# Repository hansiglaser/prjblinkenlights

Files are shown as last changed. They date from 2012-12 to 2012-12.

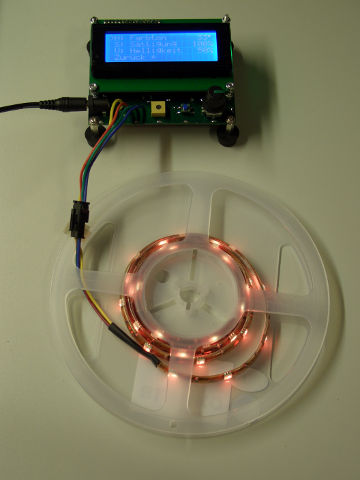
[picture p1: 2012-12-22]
doc/PrjBlinkenlights.360x480.jpg

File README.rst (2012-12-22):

Project Blinkenlights -- RGB LED Strip Controller
=================================================

**Project Blinkenlights** is a RGB LED strip controller. This repository
includes its hardware and firmware.



License
-------

    Copyright (C) 2012 Johann Glaser <Johann.Glaser@gmx.at>

    This program is free software; you can redistribute it and/or modify  
    it under the terms of the GNU General Public License as published by
    the Free Software Foundation; either version 2 of the License, or  
    (at your option) any later version.

    This program is distributed in the hope that it will be useful,
    but WITHOUT ANY WARRANTY; without even the implied warranty of
    MERCHANTABILITY or FITNESS FOR A PARTICULAR PURPOSE.  See the
    GNU General Public License for more details.

    You should have received a copy of the GNU General Public License along
    with this program; if not, write to the Free Software Foundation, Inc.,
    51 Franklin Street, Fifth Floor, Boston, MA 02110-1301 USA.

The repository includes several datasheets. Their copyright belongs to their
respective owners and are only replicated here for easier access.

The name **Project Blinkenlights** is used by numerous other organizations,
products and initiatives. This RGB LED strip controller does not have to do
anything with them. No rights on the name are requested.

Language
--------

**Project Blinkenlights** is developed for German speaking users. Therefore
its user interface and its `user manual
<prjblinkenlights/blob/master/doc/Betriebsanleitung.pdf?raw=true>`_ use the German
language. Nevertheless, all firmware source files and all hardware design
files are written in English.

Directory Structure
-------------------

  ``doc/``
    Documentation

  ``eagle/``
    Hardware design files

  ``datasheets/``
    Datasheets of the components used in the hardware design

  ``workspace/``
    Eclipse workspace with numerous testing projects

  ``workspace/PrjBlinkenlights/``
    The main Eclipse project with the full firmware

Hardware
--------

The hardware of **Project Blinkenlights** uses a TI LaunchPad MSP-EXP430 Rev.
1.5. A custom BoosterPack (see its `design files
<prjblinkenlights/tree/master/eagle/>`_) provides the facilities to control
the device, switch the LEDs, and hold an LCD display.

The LaunchPad holds an MSP430G2553 microcontroller.

Build
-----

The MSP430 microcontroller is programmed using ``msp430-gcc`` and
``mspdebug``. For details on the tool installation in Debian GNU/Linux see
my `blog post
<http://johann-glaser.blogspot.co.at/2012/10/msp430-launchpad-with-debian.html>`_.

An Eclipse workspace was created and used seamlessly with these tools for
compiling and debugging. More details to follow.

TODO
----

 - Firmware: update documentation in main.c
 - BoosterPack: change layer of wires to the LaunchPad connectors from bottom
   to top
 - Documentation: how to use Eclipse with MSP430
 - Documentation: design decisions, ideas, ... (see Zim)

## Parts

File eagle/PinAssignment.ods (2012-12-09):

Port | Timer | LaunchPad | Idee | Signal | Direction
P1.0 |  | LED gn | LCD-RS | LCD-RS | O
P1.1 | TA0.0 |  | LCD-R/W | LCD-R/W | O
P1.2 | TA0.1 |  | LCD-E | LCD-E | O
P1.3 |  | Button | PUSH | PUSH | I
P1.4 |  |  | ROTENC-A | ROTENC-A | I
P1.5 | TA0.0 |  | ROTENC-B | ROTENC-B | I
P1.6 | TA0.1 | LED rt | GATE-LCD | GATE-LCD | O | PWM
P1.7 |  |  | ROTENC-P | ROTENC-P | I
P2.0 | TA1.0 |  | GATE-R | GATE-R | O | PWM
P2.1 | TA1.1 |  | GATE-G | GATE-G | O | PWM
P2.2 | TA1.1 |  |  | LCD-D4 | B
P2.3 | TA1.0 |  |  | LCD-D5 | B
P2.4 | TA1.2 |  | GATE-B | GATE-B | O | PWM
P2.5 | TA1.2 |  |  | LCD-D6 | B
P2.6 | TA0.1 |  |  | LCD-D7 | B
P2.7

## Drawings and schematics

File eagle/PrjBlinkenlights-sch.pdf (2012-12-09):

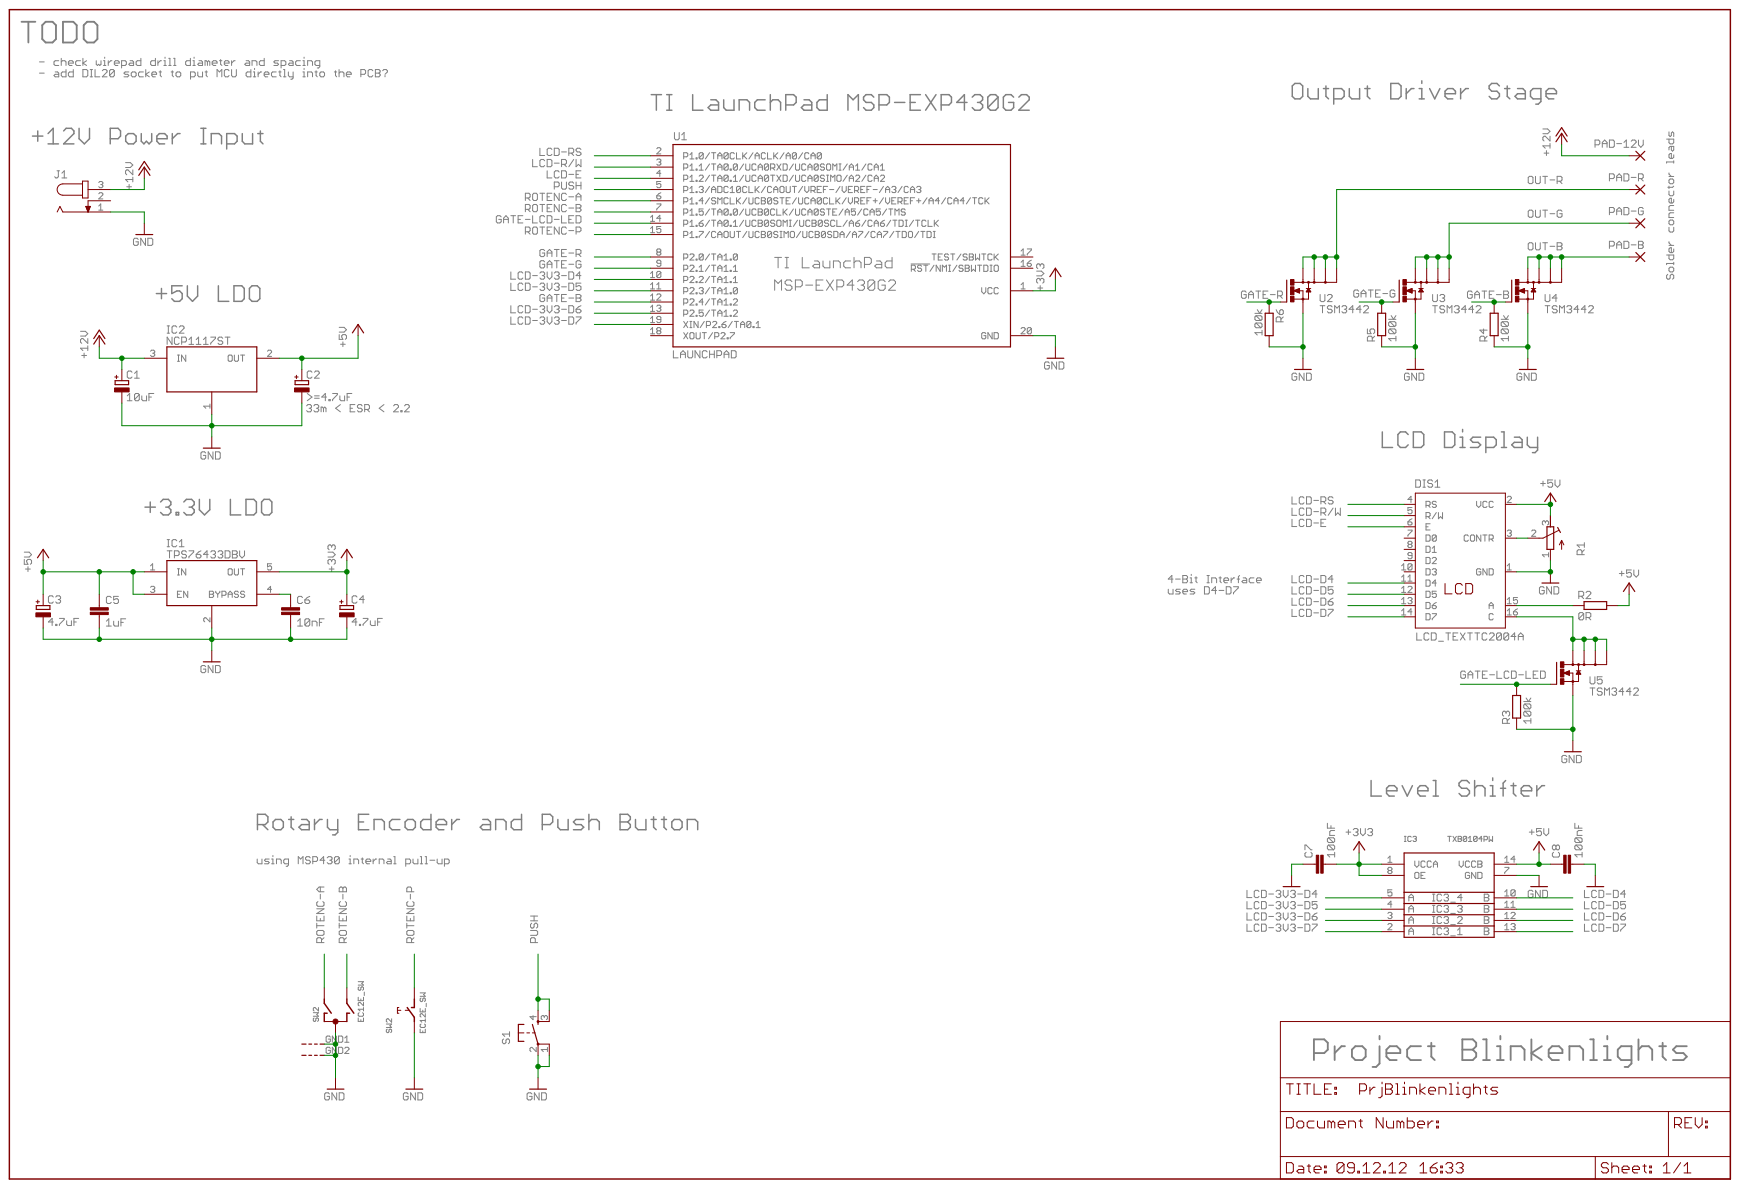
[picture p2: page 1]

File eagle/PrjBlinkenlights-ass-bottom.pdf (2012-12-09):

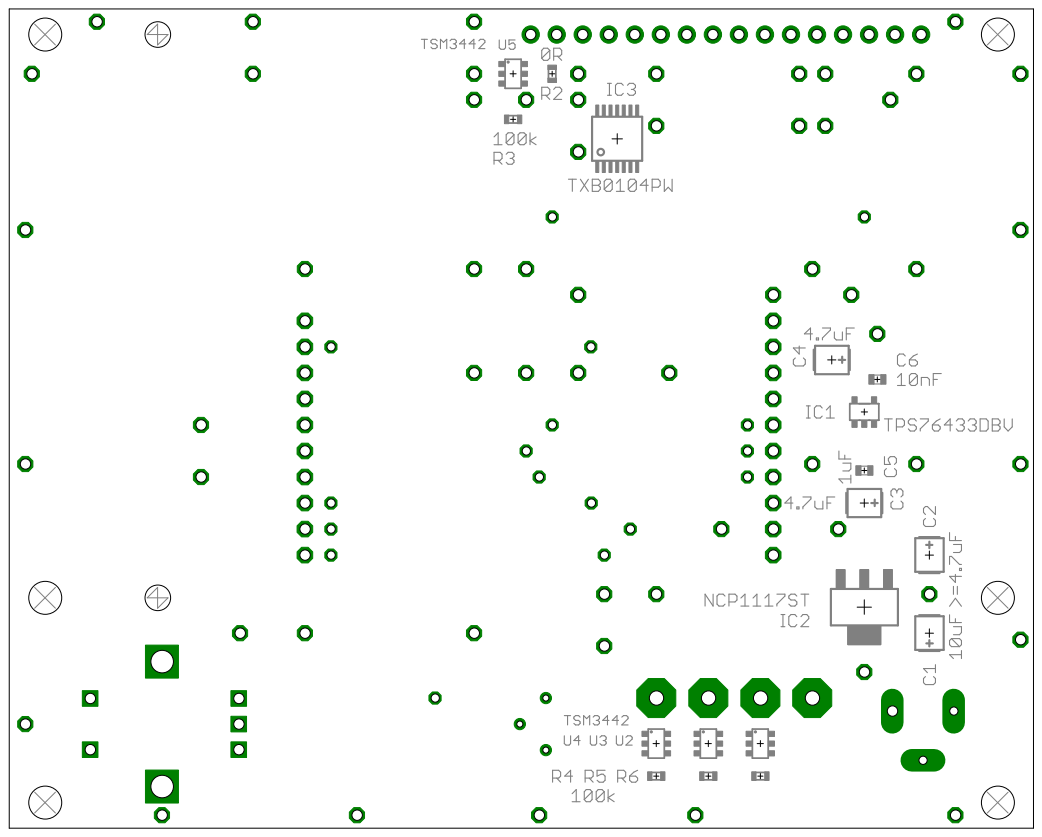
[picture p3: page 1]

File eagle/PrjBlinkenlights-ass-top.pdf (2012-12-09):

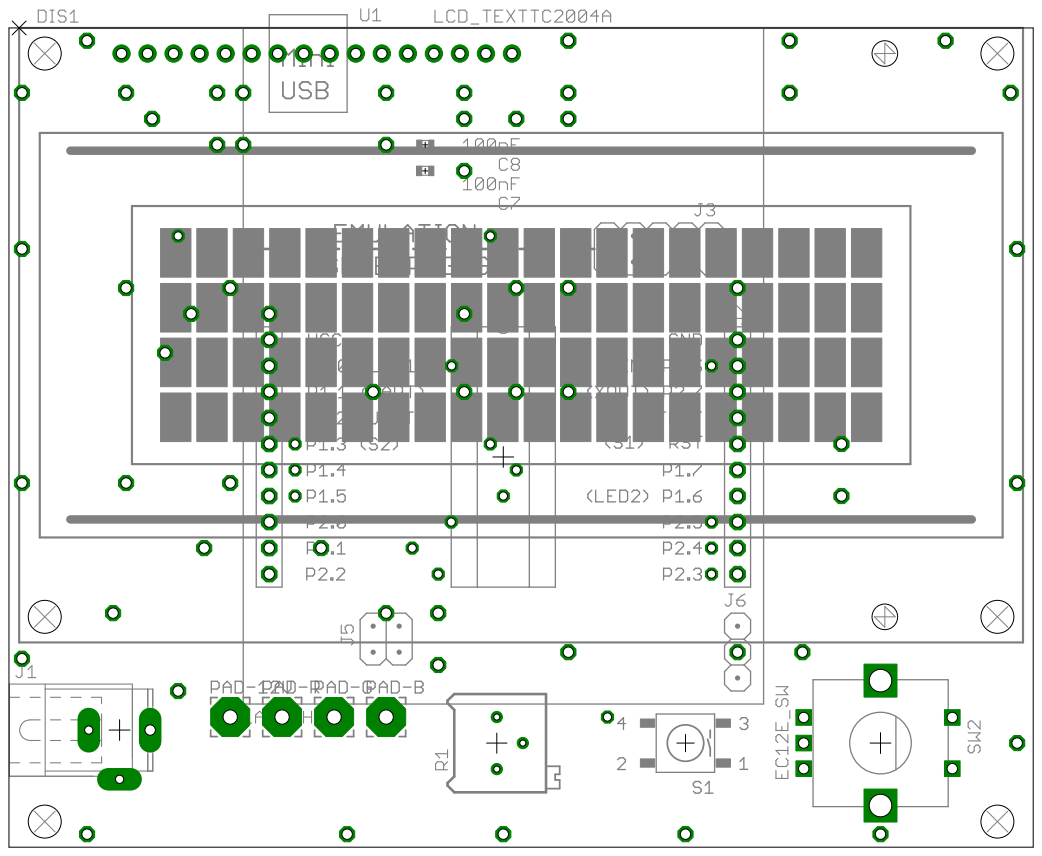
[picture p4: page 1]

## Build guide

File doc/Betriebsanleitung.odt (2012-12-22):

Project Blinkenlights

Betriebsanleitung

# Bedienung

Die Bedienung erfolgt über ein LCD-Display, einen Drehknopf mit Druckfunktion sowie einer weiteren Taste (siehe Abb. 1). Damit kann die vom LED-Streifen dargestellte Farbe eingestellt werden.

Am LCD-Display wird ein Menü angezeigt. Durch drehen des Drehknopfs wird zwischen den Menüeinträgen gewechselt. Durch Drücken auf den Drehknopf wird ein Menüeintrag ausgewählt. Je nach Typ des Menüeintrags erfolgt darauf eine entsprechende Aktion.

- Bei der Auswahl eines Untermenüs (gekennzeichnet durch einen Pfeil nach Rechts „→“) wird dieses angezeigt. Die weitere Taste dient zur Rückkehr in das vorherige Menü („Zurück“-Taste). Die Rückkehr kann auch durch Auswählen des Menüpunktes „Zurück ←“ erfolgen.
- Einige Menüpunkte dienen zur Einstellung eines Werts (z.B. der Helligkeit der LEDs). Durch Drücken des Drehknopfes wird die Einstellung dieses Werts aktiviert, der durch Drehen des Drehknopfes verändert werden kann. Nochmaliges Drücken des Drehknopfes oder der Zurück-Taste beendet die Einstellung und erlaubt wieder die Auswahl von Menüeinträgen.
- Einzelne Menüpünkte werden beim Drücken des Drehknopfes sofort aktiviert (z.B. „Aus“).

Abbildung 1: Aufbau der Hardware

# Installation

Zur Installation muss zuerst der LED Streifen mit dem Gerät verbunden werden. Danach muss das 12V-Netzteil mit der Power-Buchse verbunden werden.

# Farbeinstellungen

Ausgehend vom Hauptmenü werden unterschiedliche Farbeinstellungen ausgewählt.

- Aus: Der LED Streifen wird ausgeschaltet.
- Weiß: Ein Weiß-Ton entsprechend einer Glühbirne mit der Angabe der Helligkeit und der Farbtemperatur von 1000K (sehr rötlich) über 6600K (kühles weiß) bis 9800K (bläulich) wird angezeigt.
- RGB: Die einzelnen Farbkomponenten Rot, Grün und Blau können direkt eingestellt werden.
- HSV: Das Farbmodell „HSV“ (Hue, Saturation, Value) erlaubt die Angabe des Farbtons (einer Farbe des gesamte Regenbogens), der Sättigung (von ganz ausgebleichtem Weiß zu ganz satter Farbe) und der Helligkeit.
- Regenbogen: Die Regenbogenfarben werden in sanfter zeitlicher Abfolge dargestellt. Die Geschwindigkeit, Sättigung und Helligkeit können eingestellt werden.

# Menüstruktur

Neben den Farbeinstellungen bietet das Hauptmenü weitere Einträge (siehe Abb. 2):

- Farbe speichern: Die aktuelle Farbeinstellung wird gespeichert, so dass sie bei erneuter Aktivierung des Geräts automatisch dargestellt wird.
- Konfiguration:
  - LCD Timeout: Nach Ablauf der angegebenen Zeit wird die Hintergrundbeleuchtung des LCD Displays abgedunkelt.

Abbildung 2: Menüstruktur

# Technische Daten

### Bestandteile

- Netzteil 12V DC, mindestens 600mA (abhängig vom LED-Streifen)
- RGB LED Streifen
- Steuerung
  - TI LaunchPad MSP-EXP430G2
  - Prj. Blinkenlights BoosterPack
  - LCD Display (20x4 Zeichen)

### LED Streifen

Es können beliebige 12V DC RGB LED Streifen mit integrierten Vorwiderständen und gemeinsamer Anode (Plus-Pol) mit Strömen bis 4A pro Farbe betrieben werden, vorausgesetzt das Netzteil ist in der Lage den Gesamtstrom zu liefern. Achtung: Ab 2A pro Farbe können die Schalttransistoren heißer als 50°C werden.

### Programmierung

Das Texas Instruments MSP-EXP430 LaunchPad enthält einen MSP430G2553 Mikrocontroller. Dieser wird direkt über den Emulator-Teil des LaunchPad programmiert. Dazu müssen die Jumper „RST“ und „TEST“ verbunden werden. Nach dem Programmieren müssen beide Jumper geöffnet werden, um den Start des Geräts zu gewährleisten.

Die gesamte Firmware sowie alle Design Files sind im Internet auf GitHub unter der Adresse https://github.com/hansiglaser/prjblinkenlights/ verfügbar.

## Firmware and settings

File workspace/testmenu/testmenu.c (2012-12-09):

/**
 * Test MSP430 with the rotary encoder
 *
 * Pins:
 *  - P1.0: red LED, blinks
 *  - P1.1: rotary encoder, terminal A
 *  - P1.2: rotary encoder, terminal A
 *  - P1.3: rotary encoder, push button
 *  - P1.6: green LED, PWM
 *
 * This test program uses Timer A0 and its CCR1 to generate a PWM. This is
 * sent to P1.6 which is connected to the green LED on the LaunchPad.
 *
 *
 *     P         P
 * +--| |-------| |--+
 * |                 |
 * |                 |
 * |      -----      |
 * |     /     \     |
 * |    |   *   |    |
 * |     \     /     |
 * |      -----      |
 * |                 |
 * |                 |
 * +--| |--| |--| |--+
 *     A    B    C
 *
 * P-P is closed when the button us pressed
 *
 *
 * A-C  Off ----+     +-----+     +----
 *              |     |     |     |
 *      On      +-----+     +-----+
 *
 * B-C  Off  +-----+     +-----+     +-
 *           |     |     |     |     |
 *      On  -+     +-----+     +-----+
 *
 *           ^           ^           ^
 *           +-----------+-----------+-- detent position
 *
 * Phases: TODO
 *
 */

#include <msp430g2231.h>

typedef enum {metSimple,metSubmenu,metNumber} TMenuEntryType;

typedef int (*TMenuSimpleCallback)(void* Data);
typedef int (*TMenuNumberValueCallback)(int Delta,void* Data);
typedef void (*TMenuNumberChangeCallback)();

//typedef struct TMenuEntry TMenuEntry;

typedef struct {
  TMenuEntryType Type;
  char Label[14];
  union {
    struct {
      TMenuSimpleCallback Callback;
      void* CBData;
    } SimpleData;
    struct {
      int NumEntries;
      void* SubMenu;
    } SubMenuData;
    struct {
      char Unit;
      TMenuNumberValueCallback CBValue;
      void* CBData;
      TMenuNumberChangeCallback CBChange;
    } NumberData;
  };
} TMenuEntry;

int cbPercent(int Delta, void* Data) {
  if (Delta == 0)
    return *((int*)Data);

  int i = *((int*)Data);
  i += Delta;
  if (i < 0)
    i = 0;
  if (i > 100)
    i = 100;
  *((int*)Data) = i;
  return i;
}

int cbCircle(int Delta, void* Data) {
  if (Delta == 0)
    return *((int*)Data);

  int i = *((int*)Data);
  i += Delta;
  while (i < 0)
    i += 360;
  while (i > 360)
    i -= 360;
  *((int*)Data) = i;
  return i;
}

int cbColorTemperature(int Delta, void* Data) {
  // TODO: either as list or as values with varying step size
}

int RGBPctRed;
int RGBPctGreen;
int RGBPctBlue;

void cbRGB() {
  // TODO: update HSV values
  // TODO: update PWM
}

int HSVPctHue;
int HSVPctSaturation;
int HSVPctValue;

void cbHSV() {
  // TODO: update RGB values
  // TODO: update PWM
}



const TMenuEntry MenuWhite[] = {
    {.Type = metNumber,.Label = "Helligkeit",
        .NumberData = {.Unit = '%', .CBValue = &cbPercent, .CBData = 0 } },
    {.Type = metNumber,.Label = "Farbtemp.",
        .NumberData = {.Unit = 'K', .CBValue = 0, .CBData = 0 } },
    {.Type = metSimple,.Label = "Zurück",
        .SimpleData = {.Callback = 0, .CBData = 0}}
};

const TMenuEntry MenuRGB[] = {
    {.Type = metNumber,.Label = "Rot",
        .NumberData = {.Unit = '%', .CBValue = &cbPercent, .CBData = &RGBPctRed,   .CBChange = cbRGB } },
    {.Type = metNumber,.Label = "Grün",
        .NumberData = {.Unit = '%', .CBValue = &cbPercent, .CBData = &RGBPctGreen, .CBChange = cbRGB } },
    {.Type = metNumber,.Label = "Blau",
        .NumberData = {.Unit = '%', .CBValue = &cbPercent, .CBData = &RGBPctBlue,  .CBChange = cbRGB } },
    {.Type = metSimple,.Label = "Zurück",
        .SimpleData = {.Callback = 0, .CBData = 0}}
};

const TMenuEntry MenuHSV[] = {
    {.Type = metNumber,.Label = "H: Farbton",
        .NumberData = {.Unit = 'X', .CBValue = &cbCircle,  .CBData = &HSVPctHue,        .CBChange = cbHSV } },
    {.Type = metNumber,.Label = "S: Saettigung",
        .NumberData = {.Unit = '%', .CBValue = &cbPercent, .CBData = &HSVPctSaturation, .CBChange = cbHSV } },
    {.Type = metNumber,.Label = "V: Helligkeit",
        .NumberData = {.Unit = '%', .CBValue = &cbPercent, .CBData = &HSVPctValue,      .CBChange = cbHSV } },
    {.Type = metSimple,.Label = "Zurück",
        .SimpleData = {.Callback = 0, .CBData = 0}}
};

const TMenuEntry MenuRainbow[] = {
    {.Type = metNumber,.Label = "Geschwindigk.",
        .NumberData = {.Unit = '%', .CBValue = 0, .CBData = 0 } },
    {.Type = metSimple,.Label = "Zurück",
        .SimpleData = {.Callback = 0, .CBData = 0}}
};

// TODO: User Colors, Config

const TMenuEntry MainMenu[] = {
    {.Type = metSimple,.Label = "Aus",
        .SimpleData = {.Callback = 0, .CBData = 0}},
    {.Type = metSubmenu,.Label = "Weiss",
        .SubMenuData = {.NumEntries = 3, .SubMenu = &MenuWhite} },
    {.Type = metSubmenu,.Label = "RGB",
        .SubMenuData = {.NumEntries = 4, .SubMenu = &MenuRGB} },
    {.Type = metSubmenu,.Label = "HSV",
        .SubMenuData = {.NumEntries = 4, .SubMenu = &MenuHSV} },
    {.Type = metSubmenu,.Label = "Regenbogen",
        .SubMenuData = {.NumEntries = 2, .SubMenu = &MenuRainbow} },
};

typedef struct {
  TMenuEntry* Menu;  ///< points to a TMenuEntry[]
  int Item;   ///< Index within the menu
// TODO:
} TMenuState;

void Int2Str(int i, char* s) {
  int r;
  do {
    r = i % 10;
    i = i / 10;
    *s++ = r + '0';
  } while (i > 0);
  // TODO: reverse string
}

#define LED_R   BIT0
#define LED_G   BIT6
#define LEDS    (LED_R | LED_G)
#define LED_OUT P1OUT
#define LED_DIR P1DIR

#define ROTENC_A   BIT1   // terminal A
#define ROTENC_B   BIT2   // terminal B
#define ROTENC_P   BIT3   // push button
#define ROTENC_ALL (ROTENC_A | ROTENC_B | ROTENC_P)
#define ROTENC_IN  P1IN
#define ROTENC_DIR P1DIR
#define ROTENC_OUT P1OUT
#define ROTENC_RES P1REN
//#define ROTENC_PHASE (((ROTENC_IN & ROTENC_A)?1:0) | ((ROTENC_IN & ROTENC_B)?2:0))
#define ROTENC_PHASE ((ROTENC_IN & (ROTENC_A | ROTENC_B))>>1)
#define ROTENC_PUSH  (~(ROTENC_IN & ROTENC_P))

#define PWM_STEP 5000

// Setup LED toggle frequency
//  - SMCLK = 16MHz as setup in main()
//  - TimerA period is 65536
//  - divide by 122 -> 2 Hz -> periode on/off = 1s
#define TIMER_DIV   122

unsigned int timerCount = 0;

signed int RotEncPhase;

int main(void) {
  // Stop watchdog timer
  WDTCTL = WDTPW + WDTHOLD;

  // setup IOs for the LEDs
  LED_DIR |= LEDS;  // Set LED ports as to output direction
  LED_OUT &= ~LEDS; // Set the LEDs off
  // setup IOs for rotary encoder
  ROTENC_DIR &= ~ROTENC_ALL;   // set as input
  ROTENC_RES |=  ROTENC_ALL;   // enable pullup/pulldown resistor
  ROTENC_OUT |=  ROTENC_ALL;   // set pullup
  RotEncPhase = ROTENC_PHASE;

  // Set DCO to 16 MHz
  DCOCTL = 0;              // Select lowest DCOx and MODx settings
  // RSEL = 15 -> 15.25MHz at DCO=3 ([DS] p. 23)
  BCSCTL1 = XT2OFF | (RSEL3 | RSEL2 | RSEL1 | RSEL0);
  DCOCTL  = DCO2;   // DCO = 4 -> 15.25 * 1.08 = 16.47MHz

  // Setup TimerA
  TACTL   = TASSEL_2 | MC_2 | TAIE;    // Clk source is SMCLK, continuous mode, interrupt on reset
  TACCTL1 = OUTMOD_7;                  // CCR1 output is reset when CCR1 is reached and set when CCR0 is reached
  TACCR0  = 0x0000;                    // set to "end of periode"
  TACCR1  = 0x0000;                    // CCR1 PWM duty cycle, start at 0, will be incremented in the ISR

  P1SEL |= LED_G;                      // set green LED output as primary peripheral function

  // Clear the timer and enable timer interrupt
  __enable_interrupt();

  // LPM0 with interrupts enabled
  __bis_SR_register(LPM0_bits + GIE);

  return 0;
}

signed int Phase;
int Dec = 0;
int Inc = 0;

// Timer A0 interrupt service routine for CC1 and TA interrupt
#pragma vector = TIMERA1_VECTOR
__interrupt void Timer_A (void) {
  TACTL &= ~TAIFG;      // clear TAIFG (seems necessary!)
  // divide ISR rate for slower blinking LED
  timerCount++;
  if (timerCount >= TIMER_DIV) {
    timerCount = 0;
    // toggle
    P1OUT ^= LED_R;
  }

  // read in rotary encoder
  Phase = ROTENC_PHASE;
  int X = P1IN;
  if ((RotEncPhase == 3) && (Phase == 2)) {
    // clock-wise
    Inc++;
    if (TACCR1 < (0xFFFF - PWM_STEP)) {
      TACCR1 += PWM_STEP;
    } else {
      TACCR1 = 0xFFFF;
    }
  } else if ((RotEncPhase == 3) && (Phase == 1)) {
    // counter-clock-wise
    Dec++;
    // when decrementing, the LED sometimes flickers, this is because the timer can overflow
    if (TACCR1 > PWM_STEP) {
      TACCR1 -= PWM_STEP;
    } else {
      TACCR1 = 0;
    }
  }
  RotEncPhase = Phase;
}

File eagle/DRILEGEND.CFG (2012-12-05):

InputUserCfg = 1
SymbolLayer = 144
SymbolSize = 70
SymbolWidth = 4
TextSize = 70
TextRatio = 5
IdxFnt = 0
decMM = 1
decMIL = 0
SortHoles = 1
TolPlated = 0.02
TolNonPlated = 0.03
PlatedStatusNot = NOT
PlatedStatusBoth = BOTH
PlatedStatusYes = YES
VerticalChart = 1
HighCellFactor = 1.10
WideCellFactor = 1.10
CellOutline = 4
TitleOutline = 4
TableOutline = 8
SymbTitle = Sym
ToolTitle = N°
MMTitle = MM
MilTitle = Mils
MicTitle = Mic
QtyTitle = Qty
TypeTitle = Plated
ToleTitle = Tol
SymbRank = 1
ToolRank = 0
MMRank = 2
MilRank = 0
MicRank = 0
QtyRank = 3
TypeRank = 0
ToleRank = 0
OutputDrillRack = 0
DrillRackFile = DRILLRACK.DRL
Unit = 0
OutputUserCfg = 1
UserCfgFile = DRILEGEND.CFG

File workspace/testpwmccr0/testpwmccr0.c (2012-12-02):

/**
 * Test MSP430 PWM
 *
 * This test program uses Timer A0 and its CCR0 and CCR1 to generate a PWM.
 * These are sent to P1.1 and P1.6, respectively, which are connected to the
 * an external and the green LED on the LaunchPad, respectively.
 *
 * A trick is necessary to use CCR0 and CCR1 for PWM, because the Reset/Set
 * mode is not available for CCR0. Therefore we use the Set output mode with
 * the timer in continuous mode. The outputs are reset in the timer overflow
 * ISR (which is a bit tricky, though).
 *
 * Note that this reverses the PWM value, because the output is LOW from
 * 0..CCRx and high from CCRx..0xFFFF.
 *
 * MSP430G2231:
 *  - TA0.0 is available on P1.1, P1.5
 *  - TA0.1 is available on P1.2, P1.6, P2.6
 * MSP430G2553:
 *  - TA0.0 is available on P1.1, P1.5
 *  - TA0.1 is available on P1.2, P1.6, P2.6
 *  - TA0.2 is available on P3.0. P3.6        // damn, only available with 28-pin devices!
 *  - TA1.0 is available on P2.0. P2.3, P3.1
 *  - TA1.1 is available on P2.1, P2.2, P3.2
 *  - TA1.2 is available on P2.4, P2.5, P3.3
 *
 */

#include <msp430g2231.h>

#define LED_R   BIT0
#define LED_G   BIT6
#define LED_X   BIT1
#define LEDS    (LED_R | LED_G | LED_X)
#define LED_OUT P1OUT
#define LED_DIR P1DIR

// Setup LED toggle frequency
//  - SMCLK = 16MHz as setup in main()
//  - TimerA period is 65536
//  - divide by 122 -> 2 Hz -> periode on/off = 1s
#define TIMER_DIV   122

unsigned int timerCount = 0;

int main(void) {
  // Stop watchdog timer
  WDTCTL = WDTPW + WDTHOLD;

  // setup IOs for the LEDs
  LED_DIR |= LEDS;  // Set LED ports as to output direction
  LED_OUT &= ~LEDS; // Set the LEDs off

  // Set DCO to 16 MHz
  DCOCTL = 0;              // Select lowest DCOx and MODx settings
  // RSEL = 15 -> 15.25MHz at DCO=3 ([DS] p. 23)
  BCSCTL1 = XT2OFF | (RSEL3 | RSEL2 | RSEL1 | RSEL0);
  DCOCTL  = DCO2;   // DCO = 4 -> 15.25 * 1.08 = 16.47MHz

  // Setup TimerA
  TACTL   = TASSEL_2 | MC_2 | TAIE;    // Clk source is SMCLK, continuous mode, interrupt on reset
  TACCTL0 = OUTMOD_1;                  // CCR0 output is set when CCR0 is reached
  TACCTL1 = OUTMOD_1;                  // CCR1 output is set when CCR1 is reached
  TACCR0  = 0x0000;                    // CCR0 PWM duty cycle, start at 0, will be incremented in the ISR
  TACCR1  = 0x0000;                    // CCR1 PWM duty cycle, start at 0, will be incremented in the ISR

  P1SEL |= LED_G | LED_X;              // set green LED and external LED outputs as primary peripheral function

  // Clear the timer and enable timer interrupt
  __enable_interrupt();

  // LPM0 with interrupts enabled
  __bis_SR_register(LPM0_bits + GIE);

  return 0;
}

// Timer A0 interrupt service routine for CC1 and TA interrupt
#pragma vector = TIMERA1_VECTOR
__interrupt void Timer_A (void) {
  TACTL &= ~TAIFG;              // clear TAIFG (seems necessary!)

  // change output mode to reset the output signal
  TACCTL0 = OUTMOD_0;
  TACCTL0 = OUTMOD_1;
  TACCTL1 = OUTMOD_0;
  TACCTL1 = OUTMOD_1;

  // divide ISR rate for slower blinking LED
  timerCount++;
  if (timerCount >= TIMER_DIV) {
    timerCount = 0;
    // toggle
    P1OUT ^= (LED_R /*| LED_X*/);
  }

  // fade in with PWM from 0 to 0xFFFF within 1s
  TACCR0 -= 192;
  TACCR1 -= 269;   // 65536 / 244Hz = 268.59 -> increment by 269
}

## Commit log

2012-12-02 started PCB
    [PinAssignment.ods, PrjBlinkenlights.brd, PrjBlinkenlights.sch]
2012-12-05 mostly finished PCB
    [PrjBlinkenlights.brd, PrjBlinkenlights.sch]
2012-12-05 added some text
    [PrjBlinkenlights.brd]
2012-12-05 added drill legend
    [DRILEGEND.CFG, PrjBlinkenlights-drillegend.brd, PrjBlinkenlights-drillegend.sch]
2012-12-09 added assembly drawings
    [PinAssignment.ods, PrjBlinkenlights-drillegend.sch, PrjBlinkenlights.brd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]
2012-12-09 added PDF of schematic
2012-12-15 handling rotary encoder and buttons
2012-12-15 added LCD backlight LED fading
2012-12-15 corrected pin labels in a comment
    [testrotenc.c]
2012-12-15 switched to MSP430G2553
2012-12-15 copied over drawing of rotary encoder and signal wave forms
2012-12-17 - new semaphore system to notify ISR from main() - moved LCD backlight fade-in/-out from ISR to main() using new semaphores - set PWM timer compare registers in ISR if semaphores say so
2012-12-17 updated documentation and corrected LCD backlight fade-out
    [main.c]
2012-12-19 using correct encoding for Umlauts
    [main.c]
2012-12-20 Prevent LED flickering for small PWM values by stopping and resetting the timer before assigning new values to CCR registers. Revert simulated PWM and allow values down to 0.
    [main.c]
2012-12-20 copied integer version of RGB2HSV() to testcolor/ and corrected it
    [color.c]
2012-12-21 implemented editing menu entries (metNumber only) and updating the PWM
2012-12-22 corrected White2RGB() 16/32 bit differences on MSP430 and PC
    [color.c]
2012-12-22 removed timer ISR divider stuff, little cleanup
2012-12-22 reduced rotary encoder acceleration
2012-12-22 corrected number of submenu entries
    [main.c]
2012-12-22 fade-in RGB on power-up
2013-12-05 documented LaunchPad as debug emulator for the MSP-EXP430F5438 board
